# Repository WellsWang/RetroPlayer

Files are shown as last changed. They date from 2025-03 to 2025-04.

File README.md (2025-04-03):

# RetroPlayer

Project Video on Youtube: https://www.youtube.com/watch?v=L54KPmg54jA



RetroPlayer 项目旨在创造一个可以播放AMIGA计算机时代流行的MOD音乐格式的实体复古音乐播放器。该播放器基于ESP32实现，支持显示歌曲信息和播放控制，并通过旋转编码器进行操作。

## 功能

- **MOD音乐**：RetroPlayer可以播放存储在TF卡上的海量的AMIGA MOD音乐，MOD音乐在上世纪90年代非常流行，也是Demoscene文化中不可或缺的组成部分；
- **乐曲信息显示**： 可以通过OLED屏幕显示正在播放的乐曲的相关信息；
- **单一操控**：可以通过一个旋钮驱动旋转编码器方便地操作控制播放行为；
- **木制外壳**：虽然可以使用其它材质，但还是推荐使用实木制作，以便于得到温润厚实的手感。

## 从这里开始

### 前置准备

- 支持ESP32开发板的Arduino IDE环境
- 安装ESP8266Audio、Adafruit_SSD1306以及其依赖的函数库
- BOM表中涉及到的所有电子元器件
- 根据Gerber文件制作的PCB
- 一些板材，木材或亚克力板（2mm和1mm两种厚度规格，表层贴皮可以采用0.5mm厚度的木皮）
- 激光雕刻机或者其他能切割板材的装置（或者可以找代工商解决）
- 电烙铁和焊接耗材
- 灵巧的双手
- 耐心和面对挑战勇气

### 代码下载和说明

#### 代码下载
1. Clone the repository:
   ```sh
   git clone https://github.com/WellsWang/RetroPlayer.git
   cd RetroPlayer
   ```

 2. 直接下载zip文件，使用解压缩软件解开压缩包

#### 目录结构
- pcb  `电路设计相关`
	- BOM `物料表`
	- Gerber `PCB制作文件`
	- Schematics `电路原理图`
- enclosure `外壳设计相关`
	- 3D_Model `三维建模文件（效果验证）`
	- 2D_CAD `CAD文件，用于板材切割`
- src `源代码相关`
	- ESP8266Audio_mod_src `ESP8266Audio库中的部分需要修改定制的文件`
	- RetroPlayer25 `项目源代码`

#### 代码安装注意事项
由于ESP8266Audio库只提供了基本的文件解析和音频信号生成操作，一些我们所需要的功能并未实现，因此本项目修改了ESP8266Audio库中和MOD文件相关的部分代码并做了扩展。在编译前，需要将`src/ESP8266Audio_mod_src`目录中的文件复制到Arduino IDE使用的ESP8266Audio函数库目录中，替换掉源文件。在替换前建议对原文件进行备份。

在Windows环境下，Arduino IDE的函数库一般位于`C:\Users\用户名\Documents\Arduino\libraries`，而在Linux环境，一般位于`/home/用户名/Arduino/libraries`。

#### 电路设计安装说明
`Schematics` 目录中存放了电路原理设计图，如果您有新的想法或改进的设计，可以进行参考。

在电路图中，并未涉及锂电池充放电模块，可以使用小型的充放电一体电路模块，将5V电源输出接到H1，SW1接到开关。



对于OLED屏幕，本项目中使用的是SSD1306驱动的1.3寸128x64 SPI接口的OLED屏幕。如果需要更换其他的OLED屏幕，例如使用SH1106驱动的屏幕，需要修改源代码，建议使用u8glib库并修改对应的驱动代码。另外因为性能的原因，不建议修改为IIC接口。如果需要修改OLED屏幕的尺寸，需要同步修改外壳设计中面板的开孔大小。

在本项目中扬声器使用了4040尺寸的，4欧3W腔体扬声器。注意接线时左右扬声器线序要一致。



在电路图第三页（音频部分）中，R26和R27为两个0欧电阻，用于跳线选择。这两个电阻只需要焊接一个，建议选择只焊接R27。这种场景下，如有外接耳机、音箱插入3.5mmm音频插孔，播放器自身的扬声器将静音，只通过3.5mm音频接口输出。R26是用于测试的，如果只焊接R26，插入耳机时，扬声器依旧有声音输出，且会随着耳机插入改变声音强度。



#### 外壳设计组装说明
外壳可以使用木板或亚克力板来构建。可以使用`2D_CAD`目录中的dxf文件进行板材切割。

外壳板材除了绘制在最右侧的音箱网罩板和中央面板外，一般都使用2mm厚度的板材进行切割。



音箱网罩板和中央面板使用1mm厚度的板材切割。



切割后的板材可以参考`3D_Model`目录中的三维建模来进行组装。该文件可以使用Sketchup软件打开。

如果想遮盖板材拼接的接口，可以使用`2D_CAD/2D加工图_贴皮.dxf`这个文件对表面贴皮进行切割。贴皮可以使用厚度低于0.5mm的材料，例如胡桃木皮。

音箱网罩板使用尼龙钉与播放器主体进行卡扣连接，推荐使用3.3*13黑色尼龙钉。音箱网罩板上的蒙布需要使用专用胶水粘贴。



音箱铭牌为可选安装件。

## 未来计划与代码贡献
此项目为业余项目，虽然有很多想法，例如：
- 更完善的播放模式选择（随机，循环控制）
- 更多的歌曲信息显示（播放时长、当前音符信息）
- 更多的音乐格式（ESP8266Audio支持很多音乐格式）
- 互联网播放支持（可以直接播放modarchive.org网站的内容）
- ……还有好多想法……

但是，个人时间有限，所以，也许在未来的某一天会对此项目进行更新。

因此，非常欢迎大家fork此项目并对项目代码进行优化、改进或实现你自己的想法。
在此，先对大家的代码贡献做出感谢，谢谢大家的支持！

## 许可证
本项目基于GNU General Public License v3.0许可证发布。具体信息请参考LICENSE文件。
本项目及开发人员不对本项目中包含的所有信息、代码的质量、使用效果、带来的影响作出任何承诺，您需要自行进行判断并承担相应的责任。

## 致谢
- 灵感来自经典的 Amiga 电脑及其独特的声音处理功能。
- Earle Philhower 的 ESP8266Audio 库用于处理 MOD 文件。 (https://github.com/earlephilhower/ESP8266Audio)
- Adafriut 的 Adafriut SSD1306 库用于驱动 OLED 显示屏。(https://github.com/adafruit/Adafruit_SSD1306)

-------------------------------------------------------------------------------------------------------------------------------------

# RetroPlayer



The RetroPlayer project aims to create a physical retro music player capable of playing the popular MOD music format from the AMIGA computer era. This player is based on the ESP32, supports song information display and playback control, and is operated using a rotary encoder.

## Features

- **MOD Music**: RetroPlayer can play a vast collection of AMIGA MOD music stored on a TF card. MOD music was highly popular in the 1990s and is an essential part of the Demoscene culture.
- **Track Information Display**: The OLED screen displays relevant information about the currently playing track.
- **Single Control Interface**: Playback can be conveniently controlled using a single knob-driven rotary encoder.
- **Wooden Enclosure**: While other materials can be used, solid wood is recommended for a warm and sturdy tactile feel.

## Getting Started

### Prerequisites

- Arduino IDE environment supporting ESP32 development boards
- Installed libraries: ESP8266Audio, Adafruit_SSD1306, and their dependencies
- All electronic components listed in the BOM
- PCBs manufactured according to the provided Gerber files
- Some sheet materials: wood or acrylic sheets (2mm and 1mm thickness, with 0.5mm veneer for surface finishing)
- A laser engraver or another cutting tool (or outsourcing to a professional service)
- A soldering iron and related materials
- Dexterous hands
- Patience and courage to face challenges

### Code Download and Instructions

#### Downloading the Code
1. Clone the repository:
   ```sh
   git clone https://github.com/WellsWang/RetroPlayer.git
   cd RetroPlayer
   ```
2. Alternatively, download the ZIP file and extract it using decompression software.

#### Directory Structure
- **pcb** (Circuit Design Related)
  - **BOM** (Bill of Materials)
  - **Gerber** (PCB Manufacturing Files)
  - **Schematics** (Circuit Schematics)
- **enclosure** (Enclosure Design Related)
  - **3D_Model** (3D modeling files for visualization)
  - **2D_CAD** (CAD files for material cutting)
- **src** (Source Code Related)
  - **ESP8266Audio_mod_src** (Modified files for the ESP8266Audio library)
  - **RetroPlayer25** (Project source code)

#### Code Installation Notes
The ESP8266Audio library only provides basic file parsing and audio signal generation. Some required functionalities were not implemented, so this project modifies and extends parts of the ESP8266Audio library related to MOD files. Before compiling, copy the files from `src/ESP8266Audio_mod_src` into the ESP8266Audio library directory used by the Arduino IDE, replacing the original files. It is recommended to back up the original files before replacing them.

In Windows, the Arduino IDE libraries are typically located at:
`C:\Users\YourUsername\Documents\Arduino\libraries`

In Linux, they are usually found at:
`/home/YourUsername/Arduino/libraries`

#### Circuit Design Installation Notes
The `Schematics` directory contains circuit schematic designs. If you have new ideas or improvements, feel free to reference them.

The circuit diagram does not include a lithium battery charging/discharging module. A small integrated charging circuit module can be used, connecting the 5V power output to H1 and SW1 to the switch.



For the OLED screen, this project uses a 1.3-inch 128x64 SPI interface OLED display driven by SSD1306. If replacing it with another display, such as one driven by SH1106, modifications to the source code are required. The u8glib library is recommended for these changes. Due to performance reasons, using an I2C interface is not recommended. If changing the OLED screen size, adjust the enclosure design's panel cutout accordingly.

The speaker used in this project is a 4040-sized, 4-ohm 3W cavity speaker. Ensure that the wiring sequence for the left and right speakers is consistent.



On the third page of the circuit diagram (audio section), R26 and R27 are two 0-ohm resistors used for jumper selection. Only one of these resistors should be soldered. It is recommended to solder only R27. In this configuration, when external headphones or speakers are connected to the 3.5mm audio jack, the player's built-in speaker will be muted, and audio output will be redirected through the 3.5mm jack. R26 is used for testing purposes; if only R26 is soldered, the speaker will continue to output sound even when headphones are inserted, and the volume will change accordingly.



#### Enclosure Design and Assembly Instructions
The enclosure can be made from wood or acrylic sheets. The DXF files in the `2D_CAD` directory can be used for material cutting.

Apart from the speaker grille panel and the central panel, most parts should be cut from 2mm thick material. 



The speaker grille panel and the central panel should be cut from 1mm thick material.



After cutting, refer to the `3D_Model` directory for assembly guidance. These files can be opened using SketchUp.

To cover the joints of the assembled sheets, use the `2D_CAD/2D加工图_贴皮.dxf` file for veneer cutting. The veneer material should be less than 0.5mm thick, such as walnut veneer.

The speaker grille panel is attached to the player body using nylon pins. It is recommended to use 3.3*13mm black nylon pins. The fabric on the speaker grille should be glued with a specialized adhesive.



The speaker nameplate is an optional component.

## Future Plans and Code Contributions
This is a hobby project with many ideas for future development, such as:
- Improved playback modes (shuffle, repeat control)
- More detailed song information display (play duration, current note data)
- Support for additional music formats (ESP8266Audio supports various formats)
- Internet streaming support (direct playback from modarchive.org)
- …and many more ideas…

However, due to limited personal time, updates to this project may happen sporadically.

Thus, contributions are highly encouraged! Feel free to fork this project, optimize the code, make improvements, or implement your own ideas. Thank you in advance for your contributions and support!

## License
This project is released under the GNU General Public License v3.0. For details, refer to the LICENSE file.

The project and its developers make no guarantees regarding the quality, usability, or impact of the provided information and code. Users must evaluate and assume responsibility for their usage.

## Acknowledgments
- Inspired by the classic Amiga computers and their unique sound capabilities.
- Thanks to the ESP8266Audio library for MOD file handling (https://github.com/earlephilhower/ESP8266Audio).
- Thanks to the Adafruit SSD1306 library for OLED display handling (https://github.com/adafruit/Adafruit_SSD1306).

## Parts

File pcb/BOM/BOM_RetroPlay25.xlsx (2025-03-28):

No. | Quantity | Comment | Designator | Footprint | Value | Manufacturer Part | Manufacturer | Supplier Part | Supplier
1 | 11 | 100nF | C1,C2,C5,C6,C7,C13,C14,C17,C23,C31,C32 | C0805 | 100nF | CC0805KRX7R9BB104 | YAGEO(国巨) | C49678 | LCSC
2 | 3 | 10uF | C3,C4,C33 | C0805 | 10uF | GRM21BR61H106KE43L | muRata(村田) | C440198 | LCSC
3 | 3 | 470pF | C8,C9,C10 | C0805 | 470pF | 0805B471K500NT | FH(风华) | C1743 | LCSC
4 | 4 | 2.2uF | C11,C12,C15,C16 | C0805 | 2.2uF | CL21A225KBQNNNE | SAMSUNG(三星) | C377773 | LCSC
5 | 2 | 2.2nF | C18,C19 | C0805 | 2.2nF | CL21C222JBFNNNE | SAMSUNG(三星) | C28260 | LCSC
6 | 3 | 1uF | C20,C21,C22 | C0805 | 1uF | CL21B105KBFNNNE | SAMSUNG(三星) | C28323 | LCSC
7 | 2 | 470nF | C24,C25 | C0805 | 470nF | CL21B474KBFNNNE | SAMSUNG(三星) | C13967 | LCSC
8 | 1 | 470uF | C26 | CAP-SMD_BD6.3-L6.6-W6.6-FD | 470uF | GVT1A477M0608CNVC | HRK(鸿瑞凯电子) | C2983309 | LCSC
9 | 4 | 220pF | C27,C28,C29,C30 | C0805 | 220pF | CC0805KRX7R9BB221 | YAGEO(国巨) | C107145 | LCSC
10 | 1 | XKTF-015-G | CARD1 | TF-SMD_XKTF-015-N |  | XKTF-015-G | XKB Connection(中国星坤) | C1121874 | LCSC
11 | 1 | PJ-320D | CN1 | AUDIO-SMD_PJ-320D |  | PJ-320D | SHOU HAN(首韩) | C431535 | LCSC
12 | 1 | PZ254V-11-07P | DISPLAY | HDR-TH_7P-P2.54-V-M |  | PZ254V-11-07P | XFCN(兴飞) | C492406 | LCSC
13 | 4 | PZ254V-11-02P | H1,SPK_L,SPK_R,SW4 | HDR-TH_2P-P2.54-V-M |  | PZ254V-11-02P | XFCN(兴飞) | C492401 | LCSC
14 | 4 | BLM21PG121SN1D | L1,L2,L3,L4 | L0805 |  | BLM21PG121SN1D | muRata(村田) | C79382 | LCSC
15 | 2 | NCD0805R1 | LED1,LED2 | LED0805-R-RD |  | NCD0805R1 | 国星光电 | C84256 | LCSC
16 | 2 | BC817-25,215 | Q1,Q2 | SOT-23-3_L2.9-W1.6-P1.90-LS2.8-BR |  | BC817-25,215 | Nexperia(安世) | C39828 | LCSC
17 | 1 | 1kΩ | R1 | R0805 | 1kΩ | 0805W8F1001T5E | UNI-ROYAL(厚声) | C17513 | LCSC
18 | 7 | 470Ω | R2,R3,R10,R11,R12,R13,R14 | R0805 | 470Ω | 0805W8F4700T5E | UNI-ROYAL(厚声) | C17710 | LCSC
19 | 14 | 10kΩ | R4,R5,R6,R7,R8,R9,R15,R16,R17,R21,R22,R23,R24,R25 | R0805 | 10kΩ | 0805W8F1002T5E | UNI-ROYAL(厚声) | C17414 | LCSC
20 | 3 | 10kΩ | R18,R19,R20 | R0805 | 10kΩ | RC0805FR-0710KL | YAGEO(国巨) | C84376 | LCSC
21 | 2 | 0Ω | R26,R27 | R0805 | 0Ω | 0805W8F0000T5E | UNI-ROYAL(厚声) | C17477 | LCSC
22 | 1 | 22Ω | RN2 | RES-ARRAY-SMD_0402-8P-L2.0-W1.0-BL | 22Ω | RTA02-4D220JTH | RALEC(旺诠) | C102632 | LCSC
23 | 1 | ROTATE | SW1 | SW-TH_EC11XXXXXXXX |  | ROTATE | ALPSALPINE(阿尔卑斯阿尔派) | C470742 | LCSC
24 | 2 | TS-1088-AR02016 | SW2,SW3 | SW-SMD_L3.9-W3.0-P4.45 |  | TS-1088-AR02016 | XUNPU(讯普) | C720477 | LCSC
25 | 1 | ESP32-WROOM-32-N4 | U1 | WIFIM-SMD_ESP32-WROOM-32-N4 |  | ESP32-WROOM-32-N4 | ESPRESSIF(乐鑫) | C82899 | LCSC
26 | 1 | CH340C | U2 | SOP-16_L10.0-W3.9-P1.27-LS6.0-BL |  | CH340C | WCH(南京沁恒) | C84681 | LCSC
27 | 1 | AMS1117-3.3 | U3 | SOT-223-3_L6.5-W3.4-P2.30-LS7.0-BR |  | AMS1117-3.3 | AMS | C6186 | LCSC
28 | 1 | PAM8403 | U4 | SOP-16_L10.0-W3.9-P1.27-LS6.0-BL |  | PAM8403 | Slkor(萨科微) | C5122557 | LCSC
29 | 1 | PCM5102APWR | U5 | TSSOP-20_L6.5-W4.4-P0.65-LS6.4-BL |  | PCM5102APWR | TI(德州仪器) | C107671 | LCSC
30 | 2 | MIC5219-3.3YM5-TR | U6,U7 | SOT-23-5_L3.0-W1.7-P0.95-LS2.8-TL |  | MIC5219-3.3YM5-TR | MICROCHIP(美国微芯) | C29613 | LCSC
31 | 1 | MicroXNJ | USB1 | MICRO-USB-SMD_MICROXNJ |  | MicroXNJ | SHOU HAN(首韩) | C404969 | LCSC
32 | 2 | 扬声器 | Speaker | 40x40x22mm | 3W 4Ω | 4040腔体4欧3W-PH2.0端子 |  |  | https://item.taobao.com/item.htm?id=657030806827
33 | 1 | OLED显示屏 | OLED Diaplay | 1.3 inch 128x64 | SSD1306 SPI OLED Display | 1.3寸OLED显示屏spi接口液晶串口屏模块SH1106控制器128*64分辨率 |  |  | https://item.taobao.com/item.htm?id=569786760090
34 | 1 | 旋钮 | Knob | 22x8 (D:22mm, H:8mm) | 6mm半轴/D轴旋钮 | 铝旋钮22*8全黑编码器旋钮 |  |  | https://item.taobao.com/item.htm?id=818168080299
35 | 1 | 船型开关 | Switch | KCD5/11 |  | KCD5/11微型小船形开关 |  |  | https://item.taobao.com/item.htm?id=540512089636
36 | 1 | 锂电池充电模块 | Power Charge Module | 5v2A |  | 5V2A/2.4A充放电锂电充电模块电源 type-c口 |  |  | https://item.taobao.com/item.htm?id=748366426868
37 | 1 | 锂电池 | lithium battery

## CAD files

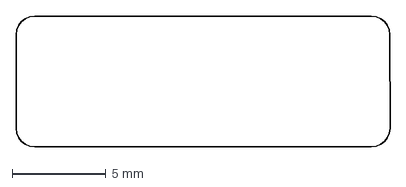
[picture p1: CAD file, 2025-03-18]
enclosure/2D_CAD/金属铭牌.dxf
20.0 x 7.00 mm

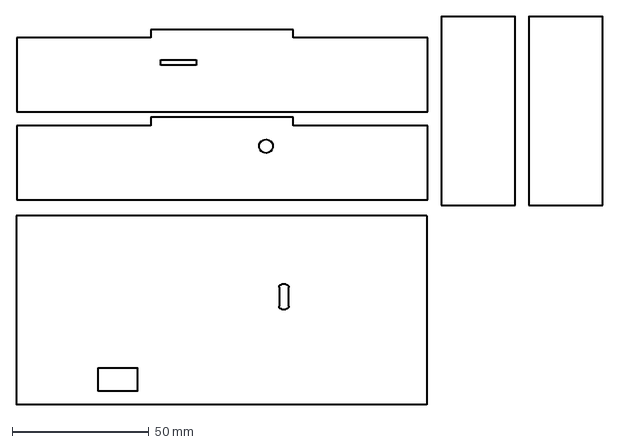
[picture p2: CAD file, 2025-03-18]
enclosure/2D_CAD/2D加工图_贴皮.dxf
214.2 x 141.9 mm

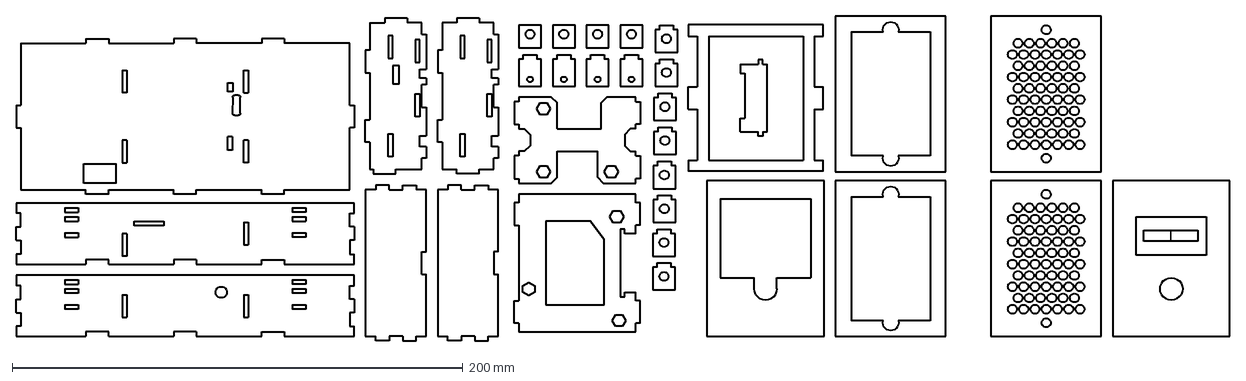
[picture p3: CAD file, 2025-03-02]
enclosure/2D_CAD/2D加工图.dxf
538.4 x 144.0 mm

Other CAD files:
enclosure/3D Model/2D加工图.skp
enclosure/3D Model/2D加工图_贴皮.skp
enclosure/3D Model/外壳.skp

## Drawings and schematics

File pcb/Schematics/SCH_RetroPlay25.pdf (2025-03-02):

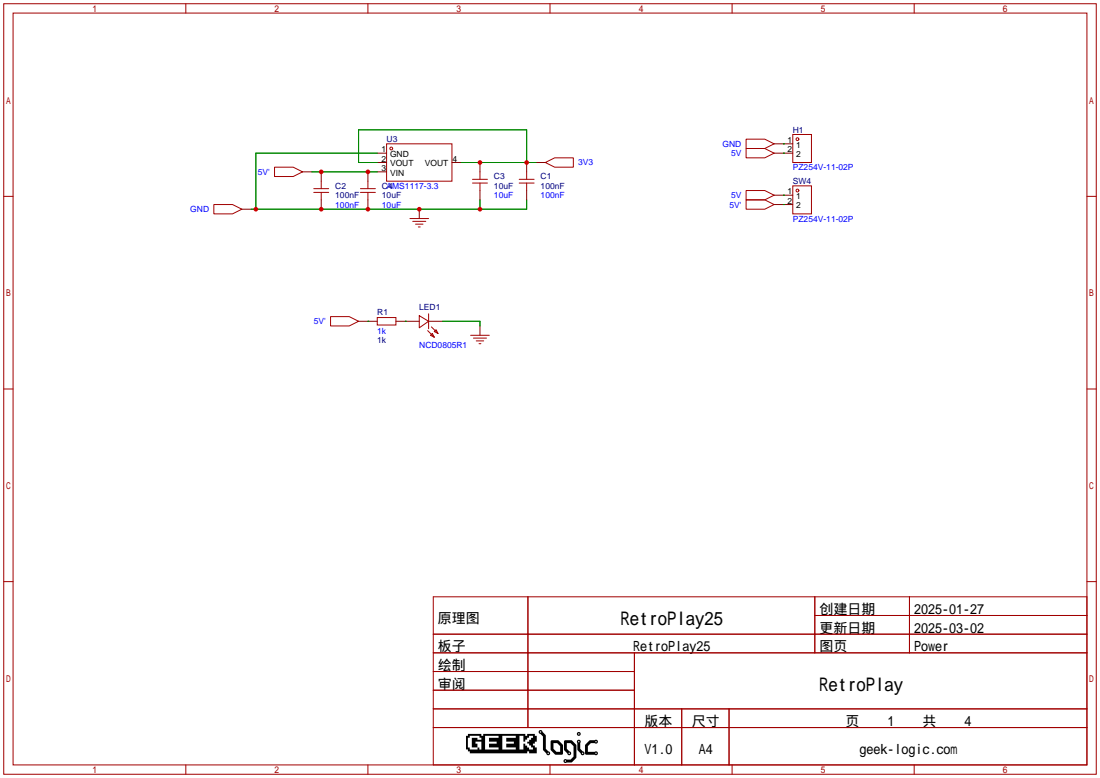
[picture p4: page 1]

原理图 | RetroPlay25 | 创建日期 | 2025-01-27

更新日期 | 2025-03-02

板子 | RetroPlay25 | 图页 | Power
绘制 | | RetroPlay
审阅

V1.0 | A4 | geek-logic.com

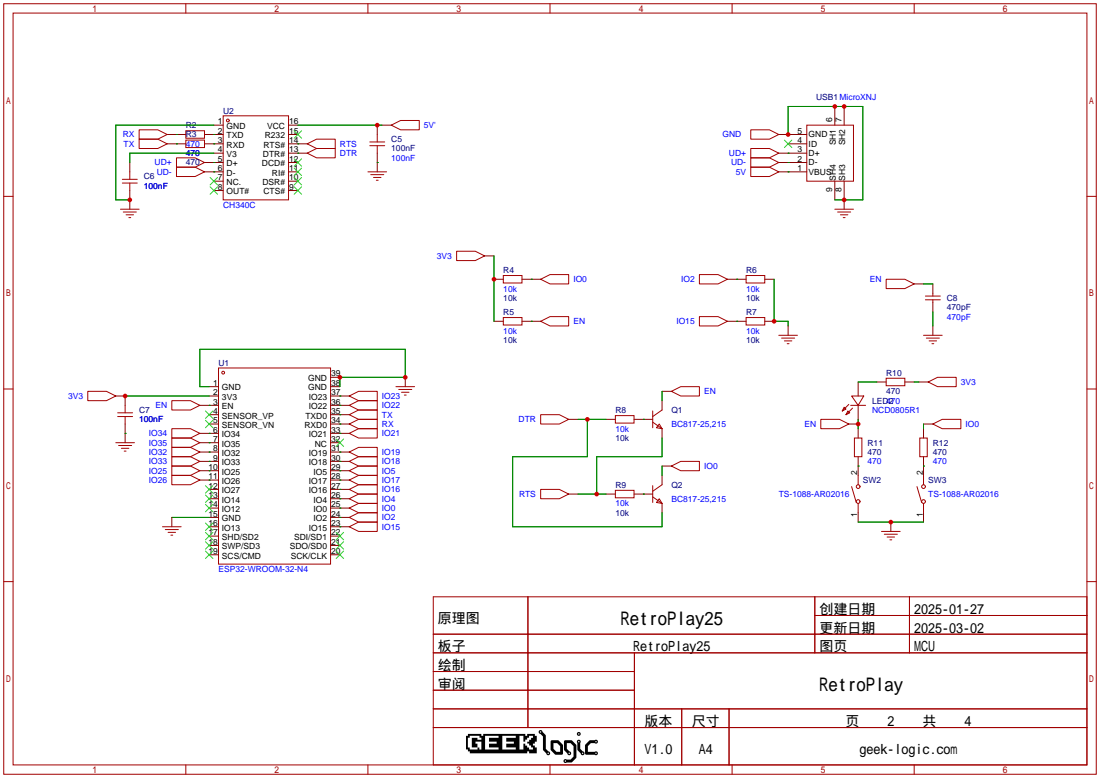
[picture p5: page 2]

DSR# 10 RI# 11 DCD# 12 DTR# 13 RTS# 14 R232 15 VCC 16

原理图 | RetroPlay25 | 创建日期 | 2025-01-27

更新日期 | 2025-03-02

板子 | RetroPlay25 | 图页 | MCU
绘制 | | RetroPlay
审阅

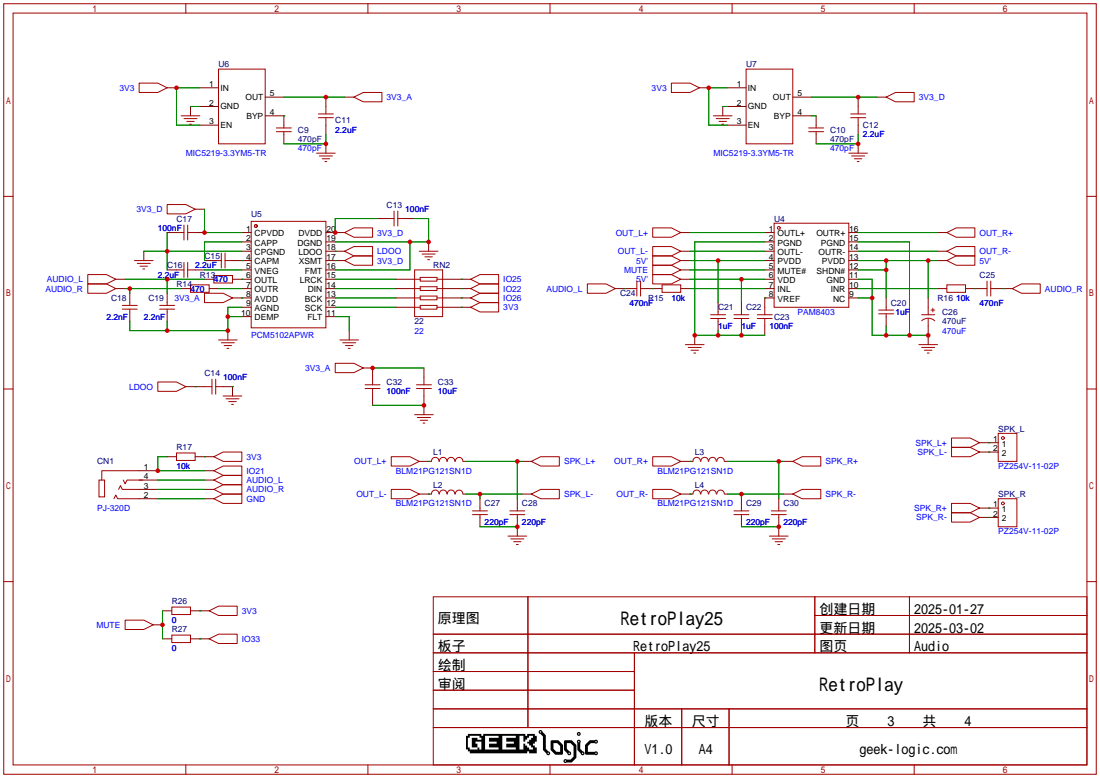
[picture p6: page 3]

INR 10 GND 11 SHDN# 12 PVDD 13 OUTR- 14 PGND 15 OUTR+ 16

原理图 | RetroPlay25 | 创建日期 | 2025-01-27

更新日期 | 2025-03-02

板子 | RetroPlay25 | 图页 | Audio
绘制 | | RetroPlay
审阅

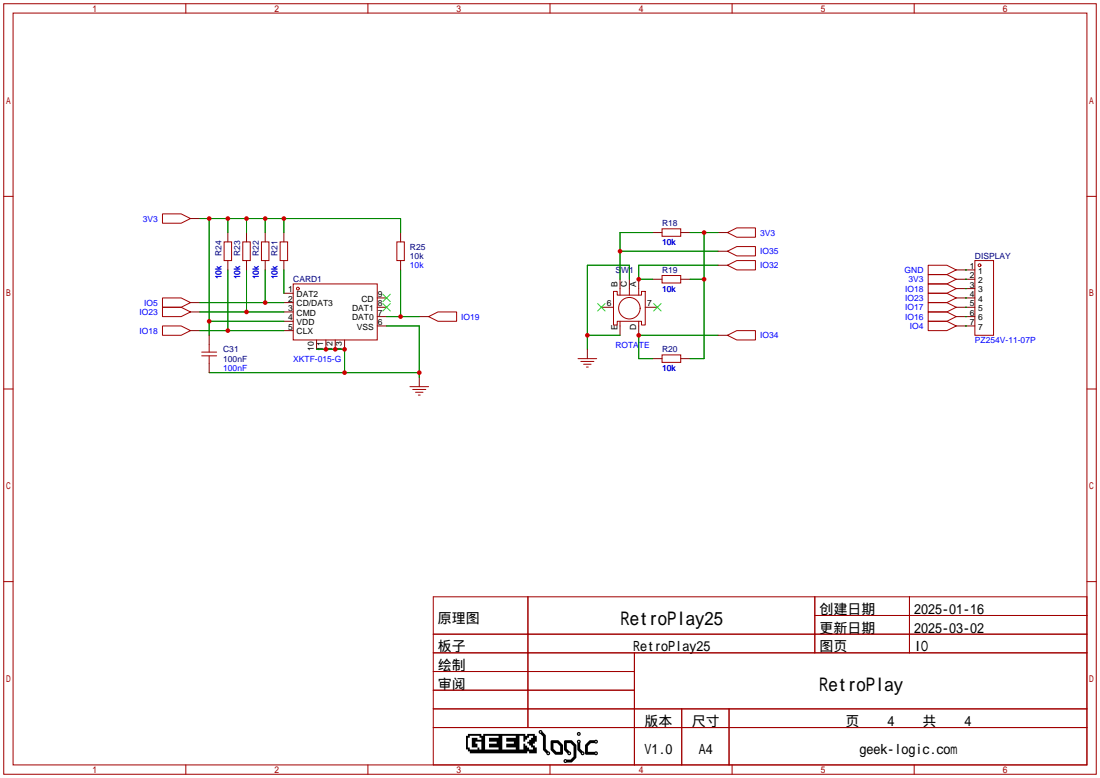
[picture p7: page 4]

原理图 | RetroPlay25 | 创建日期 | 2025-01-16

更新日期 | 2025-03-02

板子 | RetroPlay25 | 图页 | IO
绘制 | | RetroPlay
审阅

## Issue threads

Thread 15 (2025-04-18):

OLED买成1106的了

ljbstt, 2025-04-18:
大佬，能不能出个SH1106版本的程序？谢谢了。

ljbstt, 2025-04-18:
参照Adafruit_SH110X库把SSD1306都替换成SH110X，改完勉强能用，但是下面代码不能改，改了编译不通过，估计是SSD1306专用代码，只能暂时保留，不知道有什么影响？
/*
  // SSD1306_SWITCHCAPVCC = generate display voltage from 3.3V internally
  Wire.begin(SCREEN_SDA, SCREEN_SCL);
  if(!display.begin(SSD1306_SWITCHCAPVCC, SCREEN_ADDRESS)) {
    Serial.println(F("SSD1306 allocation failed"));
    for(;;); // Don't proceed, loop forever
  }
*/
  // SSD1306_SWITCHCAPVCC = generate display voltage from 3.3V internally
  // Initialize SSD1306 Display / 初始化SSD1306 OLED显示屏
  if(!display.begin(SSD1306_SWITCHCAPVCC)) {
    Serial.println(F("SSD1306 allocation failed"));
    while (1); // Don't proceed, loop forever
  }

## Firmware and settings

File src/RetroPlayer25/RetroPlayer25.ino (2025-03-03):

/*

Project RetroPlaye25
===================================================================

Try to build a retro MOD player with OLED screen.
尝试用ESP32构建支持OLED显示的复古MOD音乐播放器

Wells Wang
geek-logic.com, 2025

Release under GPLv3 License.
遵循GPLv3协议开源

Based on earlephilhower's ESP8266Audio library: https://github.com/earlephilhower/ESP8266Audio
基于earlephilhower的ESP8266Audio库：https://github.com/earlephilhower/ESP8266Audio

====================================================================

--- W I R E   D I A G R A M ---

DAC (PCM5102):
  VCC, 33V, XMT, (SCK)      -> 3.3V
  GND, FLT, DMP, FMT, SCL   -> GND
  BCLK(BCK)                 -> D26
  I2SO(DIN)                 -> D22
  LRCLK(WS/LCK)             -> D25

SD card:
  CS          -> D5
  MOSI        -> D23
  CLK         -> D18
  MISO        -> D19

OLED SSD1306 SPI Mode:
  CLK(SCK)    -> D18
  SDA         -> D23
  RES(RESET)  -> D17
  DC          -> D16
  CS          -> D4

Rotate Switch:
  SW_A        -> D32
  SW_B        -> D35
  SW_Push     -> D34

PAM8403:
  MUTE        -> D33

EARPHONE:
  CONNECT     -> D21
--------------------------------

*/

#include <Arduino.h>
#include "AudioFileSourceSD.h"
#include "AudioGeneratorMOD.h"
#include "AudioOutputI2S.h"
#include <SPI.h>
#include <Wire.h>
#include <Adafruit_GFX.h>
#include <Adafruit_SSD1306.h>

#if defined(ARDUINO_ARCH_RP2040)
    #define WIFI_OFF
    class __x { public: __x() {}; void mode() {}; };
    __x WiFi;
#elif defined(ESP32)
    #include <WiFi.h>
#else
    #include <ESP8266WiFi.h>
#endif

#define SCREEN_WIDTH    128 // OLED display width, in pixels / 显示屏宽度
#define SCREEN_HEIGHT   64 // OLED display height, in pixels / 显示屏高度

// Use hardware SPI to drive OLED / 使用硬件SPI驱动OLED屏
#define OLED_DC     16
#define OLED_CS     4
#define OLED_RESET  17
Adafruit_SSD1306 display(SCREEN_WIDTH, SCREEN_HEIGHT, &SPI, OLED_DC, OLED_RESET, OLED_CS);

// Rotary encoder settings / 旋转编码器
#define SW_P        34
#define SW_A        32
#define SW_B        35
#define SW_GAP      150000  // Jitter time, 放置信号抖动的冗余时间

// Earphone and Speaker Muter / 耳机侦测和扬声器静音
#define MUTE        33
#define EARPHONE    21

// Icon settings / 图标设置
#define ICON_WIDTH 8
#define ICON_HEIGHT 8
#define ICON_SIZE 8
static const unsigned char PROGMEM icons[] =
{ // 0, |< Prev
  0b01000010, 
  0b01000110, 
  0b01001110, 
  0b01011110, 
  0b01001110, 
  0b01000110, 
  0b01000010, 
  0b00000000, 

  // 1, || Pause
  0b01100110, 
  0b01100110, 
  0b01100110, 
  0b01100110, 
  0b01100110, 
  0b01100110, 
  0b01100110, 
  0b00000000, 

  // 2, >| Next
  0b01000010, 
  0b01100010, 
  0b01110010, 
  0b01111010, 
  0b01110010, 
  0b01100010, 
  0b01000010, 
  0b00000000,

  // 3, > Play
  0b00100000, 
  0b00110000, 
  0b00111000, 
  0b00111100, 
  0b00111000, 
  0b00110000, 
  0b00100000, 
  0b00000000, 

  // 4, |> Pause/Play
  0b01010000, 
  0b01011000, 
  0b01011100, 
  0b01011110, 
  0b01011100, 
  0b01011000, 
  0b01010000, 
  0b00000000, 

  // 5, [] Stop
  0b00000000, 
  0b01111100, 
  0b01111100, 
  0b01111100, 
  0b01111100, 
  0b01111100, 
  0b00000000, 
  0b00000000, 

  // 6, Selected
  0b11111110, 
  0b11000110, 
  0b10101010, 
  0b10010010, 
  0b10101010, 
  0b11000110, 
  0b11111110, 
  0b00000000, 

  // 7, not Selected
  0b11111110, 
  0b10000010, 
  0b10000010, 
  0b10000010, 
  0b10000010, 
  0b10000010, 
  0b11111110, 
  0b00000000, 

  // 8, Volume
  0b00000000, 
  0b00000011, 
  0b00000011, 
  0b00011011, 
  0b00011011, 
  0b11011011, 
  0b11011011, 
  0b00000000, 

  // 9, Pattern
  0b01111110, 
  0b10001111, 
  0b10110111, 
  0b10001011, 
  0b10110001, 
  0b10111011, 
  0b10111001, 
  0b01111110, 

  // 10, Channel
  0b01111110, 
  0b11001111, 
  0b10110111, 
  0b10110111, 
  0b10110001, 
  0b10110101, 
  0b11000101, 
  0b01111110, 

};

// UI Control items / UI控制控件设置
#define MAX_ITEMS 5       // Max control unit number / 控制控件数量
unsigned char menu[] = { 0, 5, 2, 7, 8};    // CU icon index array / 控件图标
static const unsigned char PROGMEM menu_x[] = { 0, 28, 56, 0, 77};    // CU position X / 控件坐标X
static const unsigned char PROGMEM menu_y[] = { 36, 36, 36, 50, 50};  // CU position Y / 控件坐标Y
String menu_items[MAX_ITEMS] = {"", "", "", "SkipJump", "Vol" };      // CU caption / 控件标题文本

// File relative / 文件相关变量
File dir, f;

// Audio process relative / 音频处理相关
AudioGeneratorMOD *mod;
AudioFileSourceSD *file = NULL;
AudioOutputI2S *out;

// Control relative / 控制相关
bool next = false;
bool prev = false;
unsigned long t, lasttime, lastkeytime;
byte last_a = 1;
byte cur_item = 1;
byte submenu = 0;
unsigned int totalfiles = 0;
unsigned int cur_file = 0;
float gain = 0.02;
float maxgain, step;
bool earphone = false;

// Display relative / 显示相关
float prg = 0.0;
float lastprg = 0.0;
char* desc; 


// -- Part 1 -- UI relative function / UI相关函数 

// ProgressBar / 进度条
void drawProgressBar(int x, int y, int length, float percent, int mode)
{
  int pct = int(percent / 100.0 * (length));
  //if (mode == 0) display.drawRect(x, y, length, 4, SSD1306_WHITE);              // （绘制进度条边框，已取消此功能）
  if (mode < 2) display.fillRect(x , y, pct , 2, SSD1306_WHITE);                  // 增长时绘制白色进度条
  if (mode == 2) display.fillRect(x + pct, y, length - pct, 2, SSD1306_BLACK);    // 缩减时用黑色擦除多余的进度
}

// Icon / 图标
void drawIcon(int x, int y, byte id, int color) {
  unsigned char icon[ICON_SIZE];
  for (int i=0; i<ICON_SIZE; i++){
    icon[i] = pgm_read_word_near(icons + id * ICON_SIZE + i);   //按索引号读取图标数据
  }
  display.drawBitmap(x,y,icon, ICON_WIDTH, ICON_HEIGHT, color);
}

// Button / 按钮
void drawButton(int x, int y, int size, byte id, bool active)
{
  int color;
  if (active) { //激活按钮，绘制实心圆角矩形
    color = SSD1306_BLACK;
    display.fillRoundRect(x, y, 8 * (size + 2), 9, 3, SSD1306_WHITE);

  } else {  // 非激活按钮，先绘制黑色实心圆角矩形（擦除原图形）后再绘制空心圆角矩形
    color = SSD1306_WHITE;
    display.fillRoundRect(x, y, 8 * (size + 2), 9, 3, SSD1306_BLACK);
    display.drawRoundRect(x, y, 8 * (size + 2), 9, 3, SSD1306_WHITE);
  }
 for (int i=0; i<size; i++) // 绘制图标，可以用多个连续图标拼接按钮上的图形
   drawIcon(x + 8 * (i + 1), y + 1, id + i, color);
}

// Option / 选项
void drawOption(int x, int y, byte id, byte cap_index, bool active )
{
  int color1, color2;
  if (active) { //激活时反色显示
    color1 = SSD1306_BLACK;
    color2 = SSD1306_WHITE;
  } else {
    color1 = SSD1306_WHITE;
    color2 = SSD1306_BLACK;
  }

  display.fillRect(x, y, menu_items[cap_index].length() * 6 + 10 , 8, color2);  //用背景色擦除
  display.setTextColor(color1);
  drawIcon(x, y , id, color1);
  display.setCursor(x + 10, y);
  display.print(menu_items[cap_index]);
}

// Control Unit Item / 绘制单个控件
void drawMenuItem(byte i, bool active){
  if (menu_items[i].length() > 0)   // 如果控件的标题文本为空，则画按钮，否则画选择项
    drawOption(menu_x[i], menu_y[i], menu[i], i, active);
  else
    drawButton(menu_x[i], menu_y[i], 1, menu[i], active);
}

// Control Panel / 绘制控件区
void drawMenu(){
  bool active;
  for (int i = 0; i < MAX_ITEMS; i++){
    if (cur_item == i)  // 判断当前空间是否激活
      active = true;
    else
      active = false;
    drawMenuItem(i, active);
  }
} 

// UI Initialize / UI界面初始化 
void drawUI()
{
  display.clearDisplay();
  display.fillRect(0, 0, display.width() - 1 , 8, SSD1306_WHITE);
  display.setTextSize(1);  
  display.setTextColor(SSD1306_BLACK);
  display.setCursor(0, 0);
  display.println(F(":: RETROPLAYER 25 ::"));
  display.setTextColor(SSD1306_WHITE);
  display.drawLine(0, 31, display.width() - 1, 31, SSD1306_WHITE);
  drawIcon(86, 36, 10, SSD1306_WHITE);
  drawIcon(106, 36, 9, SSD1306_WHITE);
  drawMenu();
  drawProgressBar(0, 62, 128, 0.0, 1);
  updateGainInfo();
  display.display();
}

// File Description / 文件注释信息
void printDescription(uint8_t x, uint8_t y)
{ 
  // 将第21字节设置为0x00，以显示前20个字节
  uint8_t t = desc[20];
  desc[20] = 0;
  display.setCursor(x, y);
  display.print(desc);
  // 还原第20字节后，将第41字节设置为0x00，以显示后20字节
  desc[20] = t;
  display.setCursor(x, y + 8);
  t = desc[40];
  desc[40] = 0;
  display.print(desc + 20);
  // 还原第41字节内容
  desc[40] = t;
}

// Update Music Info / 更新音乐的相关信息
void updateSongInfo(String name, int ch, int pt)
{
  // 文件名信息
  name.toUpperCase();
  name = name.substring(0, name.length() - 4);
  if (name.length() > 21) name = name.substring(0, 18) + "...";   //长文件名截短
  display.fillRect(0, 0, display.width()-1, 8, SSD1306_WHITE);
  display.setTextColor(SSD1306_BLACK);
  display.fillRect(0, 11, display.width()-1, 16, SSD1306_BLACK);
  display.setCursor((display.width()- 6 * name.length()) / 2 - 1, 0);
  display.println(name); 

  // 文件注释信息
  display.setTextColor(SSD1306_WHITE);
  printDescription(0, 11);

  // 通道数量
  display.fillRect(96, 36, 8, 8, SSD1306_BLACK);
  display.setCursor(96, 36);
  display.print(ch);

  // 格式数量
  display.fillRect(116, 36, 12, 8, SSD1306_BLACK);
  display.setCursor(116, 36);
  display.print(pt);

  // 完成绘制更新显示
  display.display();
}

// Volume / 音量
void updateGainInfo()
{
  int vol = int(gain * 100 / maxgain);  //当前音量百分比
  if (vol > 100) vol = 100;

  display.fillRect(110, 50, 18, 8, SSD1306_BLACK);
  display.setCursor(110, 50);
  display.setTextColor(SSD1306_WHITE);
  display.print(vol); 
  display.display();
}

// Update ProgressBar / 更新进度条
void updateProgress()
{
  prg = float(mod->GetPlayPos()) / mod->GetSongLength() * 100;
  if (prg > lastprg) {                      // 进度增加
    drawProgressBar(0, 62, 128, prg, 1);
    display.display();
    lastprg = prg;
  } else if (prg < lastprg) {               // 进度回退
    drawProgressBar(0, 62, 128, prg, 2);
    display.display();
    lastprg = prg;
  }
}

// -- Part 2 -- Control Part / 控制部分

// update Play Button / 更新播放按键的状态
void startPlay()
{
  // 将停止播放状态变更为播放状态 （根据控件1的图标编号来判断是否处于播放状态）
  if (menu[1] == 3) {         // 编号为 3 ，播放箭头，图标为 ">"时，处于停止播放状态
    menu[1] = 5;              // 编号为 5 ，方块，按钮上图标为“[]”时，处于正在播放状态 
    drawMenuItem(1, false);
    display.display();
  }
}

// Stop and Start Playing / 停止或开始播放
void toggleStopStart()
{
  //停止或开始播放音乐
  if (mod->isRunning()){      // 处于播放状态
    mod->stop();
    menu[1] = 3;              // 将图标设为编号 3 ，播放箭头，图标为 ">"时，处于停止播放状态
  } else {
    file->open(("/"+String(f.name())).c_str());   // 重新打开文件
    mod->begin(file, out);
    menu[1] = 5;              // 将图标设为编号 5 ，方块，按钮上图标为“[]”时，处于正在播放状态 
  }

  drawMenuItem(cur_item, true);
  display.display();
}

// Toggle SkipJump Function / 切换强制跳过跳转的功能
void toggleSkipJump()
{
  mod->SetSkipJump(!mod->GetSkipJump());  // 切换SkipJump标志的值
  if (menu[3]==6)                         // 切换显示的图标
    menu[3] = 7;
  else
    menu[3] = 6;
  drawMenuItem(cur_item, true);
  display.display();
}

// Close Music File / 停止播放关闭音乐文件
void closeMusic()
{
    //结束当前播放
    if (mod->isRunning()) mod->stop();
    file->close();
}

// Open Music File / 打开并播放音乐文件
void openMusicFile()
{
  // 结束当前播放
  closeMusic();

  // 打开文件
  if (file->open(("/"+String(f.name())).c_str())) { 
    Serial.printf_P(PSTR("Playing '%s' from SD card...\n"), f.name());
    out->SetGain(gain);
    mod->begin(file, out);
    desc = mod->GetFileDescription();
    Serial.println(desc+20);
    updateSongInfo(f.name(), mod->GetChannelNumber(), mod->GetPatternNumber());
    Serial.print(mod->GetChannelNumber());
    Serial.print(" / ");
    Serial.println(mod->GetPatternNumber());
    Serial.println(mod->GetSongLength());
    delay(1000);
  } else {
    Serial.printf_P(PSTR("Error opening '%s'\n"), f.name());
  }
}

// Rewind Folder / 跳转到文件目录开始
void rewindFolder()
{
  // 结束当前播放
  closeMusic();

  Serial.println(F("Playback from SD card done\n"));
  //重新打开目录，回到开头
  dir = SD.open("/"); 
  delay(1000);
}

// update Button / 更新按钮状态
void updateButton(int step)
{
  drawMenuItem(cur_item, false);        // 重新绘制当前控件为未激活状态
  cur_item = (cur_item + step + MAX_ITEMS) % MAX_ITEMS; // 当前激活的控件编号变更，超过范围时从头部或尾部循环
  drawMenuItem(cur_item, true);         // 绘制新的激活的控件
  display.display();
}

// Volume Control / 音量控制
void changeVolume(float step)
{
  if (gain >= 0 && gain <= maxgain) {
    gain += step;             // 音量调整
    if (gain < 0) gain = 0;
    if (gain > maxgain) gain = maxgain;
    out->SetGain(gain);
    updateGainInfo();         // 更新音量显示
    //Serial.println(gain);
  }  
}

// -- Part 3 -- Initialize / 初始化

void setup()
{
  WiFi.mode(WIFI_OFF); //WiFi.forceSleepBegin();
  Serial.begin(115200);
  delay(100);
  
  // Rotary encoder / 旋转编码器
  pinMode(SW_A, INPUT);
  pinMode(SW_B, INPUT);
  pinMode(SW_P, INPUT);
  
  // Earphone detect & Speaker Muter / 耳机检测和扬声器静音
  pinMode(MUTE, OUTPUT);
  pinMode(EARPHONE, INPUT);
  digitalWrite(MUTE, HIGH);
  earphone = true;
  maxgain = 0.3;
  step = 0.01;

  audioLogger = &Serial;
  file = new AudioFileSourceSD();   // Music source from SD file / 音乐来源为SD/TF卡文件
  out = new AudioOutputI2S();       // Use external I2S DAC / 使用外部DAC
  mod = new AudioGeneratorMOD();    // MOD parser / MOD文件解析器

/*
  // SSD1306_SWITCHCAPVCC = generate display voltage from 3.3V internally
  Wire.begin(SCREEN_SDA, SCREEN_SCL);
  if(!display.begin(SSD1306_SWITCHCAPVCC, SCREEN_ADDRESS)) {
    Serial.println(F("SSD1306 allocation failed"));
    for(;;); // Don't proceed, loop forever
  }
*/
  // SSD1306_SWITCHCAPVCC = generate display voltage from 3.3V internally
  // Initialize SSD1306 Display / 初始化SSD1306 OLED显示屏
  if(!display.begin(SSD1306_SWITCHCAPVCC)) {
    Serial.println(F("SSD1306 allocation failed"));
    while (1); // Don't proceed, loop forever
  }

  drawUI();

  // Initialize SD / 初始化SD文件系统
  if (!SD.begin(5, SPI, 8000000)) {
    Serial.println("SD initialization failed!");
    display.setCursor(0, 12);
    display.println(F("SD INIT FAILED!"));
    display.display();
    while (1); // Don't proceed, loop forever
  }

  // Get total MOD file numbers / 获取MOD文件总数
  dir = SD.open("/"); 
  while(f = dir.openNextFile()){
    if (String(f.name()).endsWith(".mod"))
      totalfiles++;
  }
  //Serial.print("Total Files: ");
  //Serial.println(totalfiles);

  // MOD file settings / MOD文件设置
  mod->SetBufferSize(6*1024);
  mod->SetSampleRate(33000);
  mod->SetStereoSeparation(32);

  // Initialize key/button timestamp / 初始化按键时间戳
  t = micros();
  lasttime = t;
  lastkeytime = t;
}

// -- Part 4 -- Infinite Big Loop / 无限循环体
void loop()
{
  // 耳机侦测，低电平为耳机插入
  if (digitalRead(EARPHONE)!=earphone){   // 耳机插孔状态有变化
    earphone = !earphone;
    if (!earphone){   // 耳机插入，由于没有经过功放芯片将放大倍数调大，适应耳机的音量比例关系
      maxgain = 3;
      step = 0.1;
      gain = gain * 10;
    } else {          // 耳机拔出，由于扬声器经过功放芯片输出，因此缩小增益倍数，适应扬声器的音量比例
      maxgain = 0.3;
      step = 0.01;
      gain = gain / 10.0;
      if (gain > maxgain) gain = maxgain;
    }
    out->SetGain(gain);
    digitalWrite(MUTE, earphone); // 扬声器静音也是低电平有效，同步耳机侦测信号，插入耳机时扬声器静音，拔出耳机时使用扬声器播放
  }

  // 串口调试控制
  int cmd = 0;
  if (Serial.available() > 0) {
    // read the incoming byte:
    cmd = Serial.read();
    switch(cmd){
      case 'p': prev = true;  //前一首
                break;
      case 'n': next = true;  //下一首
                break;
      case '+': gain += step;  //音量加
                out->SetGain(gain);
                break;
      case '-': gain -= step; //音量减
                out->SetGain(gain);
                break;
      case 'j': mod->SetSkipJump(!mod->GetSkipJump());  //跳过Jump开关
                break;
    }
  } 

  // 旋转编码器处理
  byte a;
  a = digitalRead(SW_A);
  if (a != last_a){
    t = micros(); 
    last_a = a;
    if (t - lastkeytime > SW_GAP ){             // 防止信号抖动
      if (digitalRead(SW_B) != a) {             // 向左旋转
        if(submenu == 0){                       // 在根级控件控制中
          updateButton(-1);                     // 回到前一个按钮
        } else if (submenu == 1) {              // 如果在一级子控件控制中
          switch(cur_item) {
            case 4:                             // 当前激活控件编号4 - 音量控制
                    changeVolume(-step);        // 降低音量
                    break;
          }
        }
        //Serial.println(cur_item);
      } else {                                  // 向右旋转
        if(submenu == 0){                       // 在根级控件控制中
          updateButton(1);                      // 下一个按钮
        } else if (submenu == 1) {              // 如果在一级子控件控制中
          switch(cur_item) {
            case 4:                             // 当前激活控件编号4 - 音量控制
                    changeVolume(step);         // 提高音量
                    break;
          }
        }
        //Serial.println(cur_item);
      }
      lastkeytime = t;
    }
    // 修正延迟导致的波形匹配错误
    a = digitalRead(SW_A);
    last_a = a;
    ///////
  }

  // 按下旋转编码器，执行功能
  if (!digitalRead(SW_P)){
    t = micros();
    if (t - lastkeytime > SW_GAP * 2){  // 防止信号抖动
      if (submenu == 0){                // 在根级控件控制中按下按键
        switch (cur_item){
          case 0:
                  prev = true;
                  startPlay();          // 如果为停止播放状态，将状态修改为播放状态
                  break;
          case 1:
                  toggleStopStart();    // 停止播放或开始播放
                  break;
          case 2:
                  next = true;
                  startPlay();          // 如果为停止播放状态，将状态修改为播放状态
                  break;
          case 3:
                  toggleSkipJump();     // 切换强制跳过跳转功能
                  break;
          case 4:
                  submenu = 1;          // 进入下一级子控制
                  break;
        }
      } else if (submenu == 1) {        // 在一级子控制中
        switch (cur_item){
          case 4:                       // 当前激活控件编号4 - 音量控制 
                  submenu = 0;          // 按下按键完成音量设置，退回到根级控制
        }
      }
      lastkeytime = t;
    }
  } 

  // 音乐切换控制
  if ((mod) && mod->isRunning() && !(next || prev) ) { // 正在在播放音乐，且未按下上一首、下一首

    t = micros();

    if (!mod->loop()) mod->stop();
    if ((t - lasttime) > 100000 ) { //  定时更新
      updateProgress();             //  更新进度条
      lasttime = t;
    }
   } else if (menu[1] != 3) {       //  处于非停止播放状态（可能一首曲子播完了或者按下了上一首、下一首按钮），控件1的图标为“>”（编号3）时，为停止播放状态
    next = false;
    Serial.printf("MOD done\n");
    delay(1000);
    if (prev){                                          // 如果是按下了上一首的按钮
      unsigned int tgt_file, t;
      if (cur_file > 1)                                 // 目标曲目号为前一号，如果已是第一首曲子，则为最后一首曲子的编号
        tgt_file = cur_file - 1;
      else
        tgt_file = totalfiles;

      dir = SD.open("/");                               // 重新打开目录
      t = 0;
      while (t < tgt_file - 1) {                        // 从第一个文件开始遍历到前【两】首曲子
        f = dir.openNextFile();
        if (f)     
          if (String(f.name()).endsWith(".mod"))        // 只统计.mod结尾的文件（MOD文件）
            t++;
      }
      cur_file = tgt_file - 1;
      prev = false;
    }
    while (f = dir.openNextFile()){                     // 找到下一首MOD文件
      if (String(f.name()).endsWith(".mod")) break;     // （如果按下下一首的按钮，直接执行这段代码，找到下一首曲子；
    }                                                   // 如果是按了上一首按钮，前面遍历到前两首曲子，这里执行到下一首正好就是当前曲目的上一首）
    
    if (f) {      
      cur_file++;                                       // 当前曲目号加一
      openMusicFile();                                  // 打开并播放新的音乐文件
    } else {                                            // 没有下一个文件了
      cur_file = 0;                                     // 曲目号为0
      rewindFolder();                                   // 跳转到目录开始
    }       
  }
}

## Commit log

2025-03-01 Initial Commit: Add source code alpha version.
    [BOM_RetroPlay25_RetroPlay25_2025-02-15.xlsx]
2025-03-02 Refresh BOM; Add schematics and gerber files; Add shell CAD files.
    [2D加工图.dxf, BOM_RetroPlay25.xlsx, 外壳.skp]
2025-03-03 Adjust Error Msg position
    [RetroPlayer25.ino]
2025-03-03 Bug Fix: Volume can't be changed if at 0 or max level.
    [RetroPlayer25.ino]
2025-03-18 Update wooden shell CAD files.
    [2D加工图.skp, 2D加工图_贴皮.dxf, 2D加工图_贴皮.skp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]
2025-03-28 Update BOM
    [BOM_RetroPlay25.xlsx]
2025-03-28 Update dir structure
    [2D加工图.dxf, 2D加工图.skp, 2D加工图_贴皮.dxf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]
